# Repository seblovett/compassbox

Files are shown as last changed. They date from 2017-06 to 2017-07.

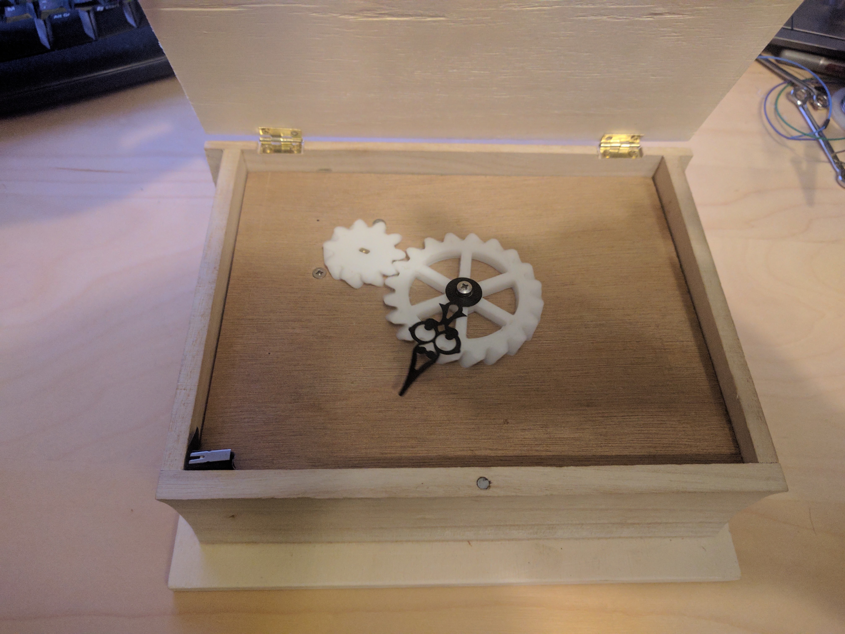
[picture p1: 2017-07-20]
Photos/IMG_20170703_221253.jpg

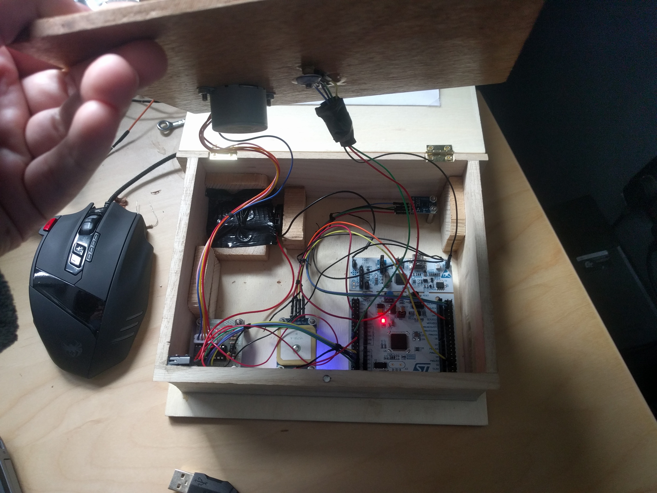
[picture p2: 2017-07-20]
Photos/IMG_20170714_074107.jpg

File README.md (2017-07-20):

# CompassBox

This is a box which I made as a wedding present. When functioning it points back to where the couple exchanged their vows. 

I originally got the idea from http://hackaday.com/2016/11/05/personal-compass-points-to-your-spawn-point/. The one aspect I didn't like about the original design was the use of the servo motor and meant it could not turn continually. 

I opted for the use of a stepper motor and integrate a zero location sensor which is a opto sensor. 

4 PCBs in the box under the false bottom:
 - STM32 Nucleo board
 - I2C Magnetometer 
 - GPS
 - Motor driver

There is also a microswitch which controls the power to the entire system.

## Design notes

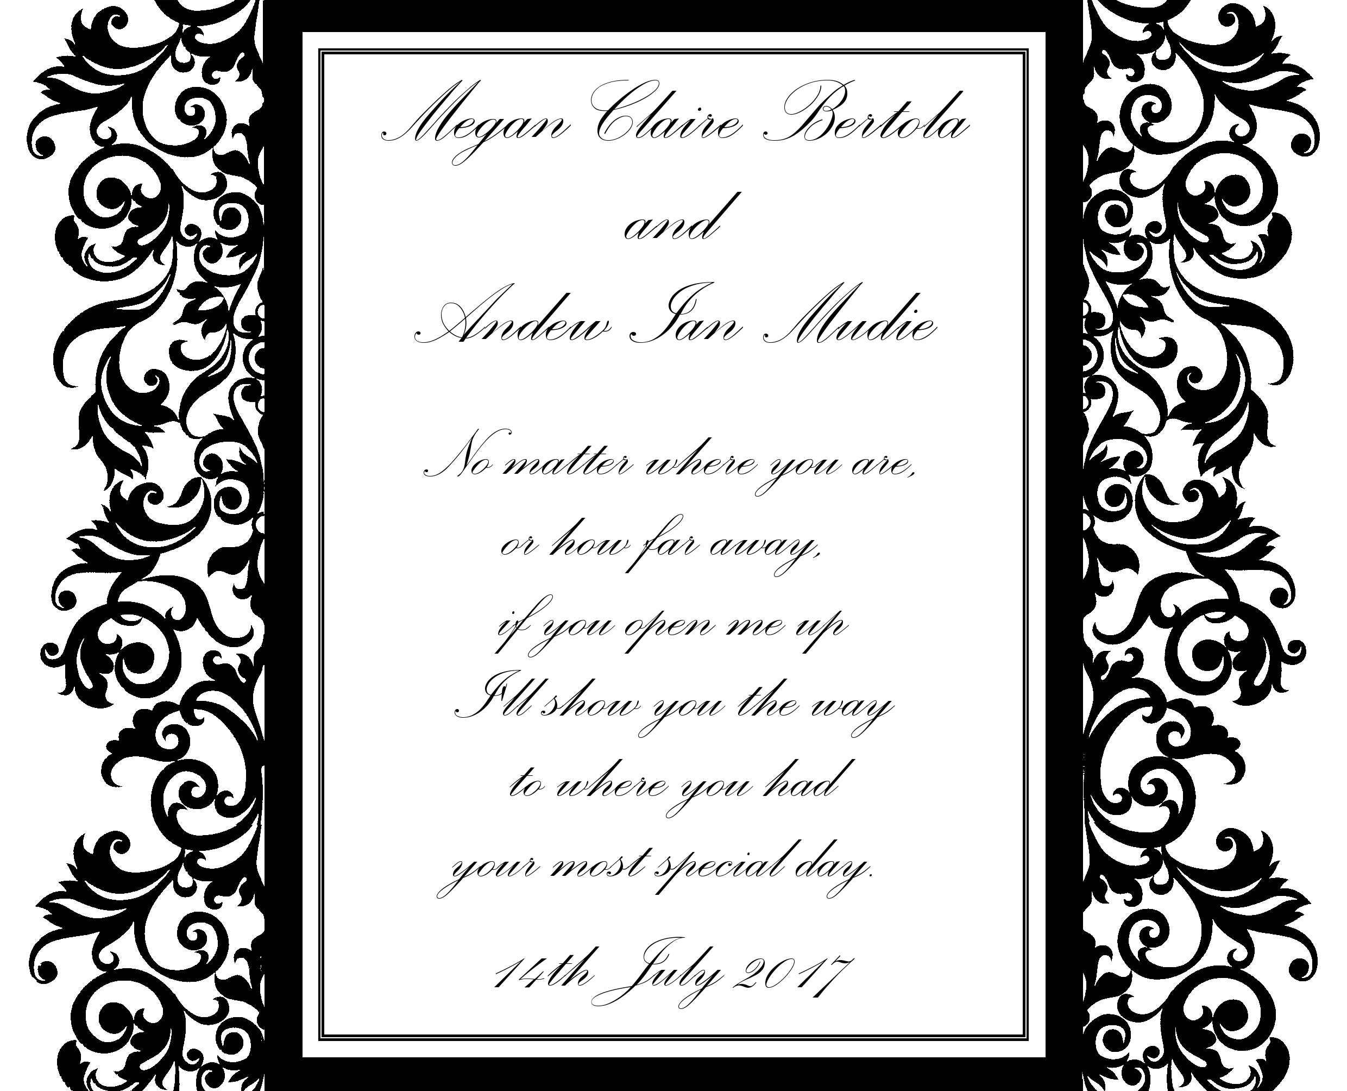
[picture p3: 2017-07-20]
Images/AandM.png

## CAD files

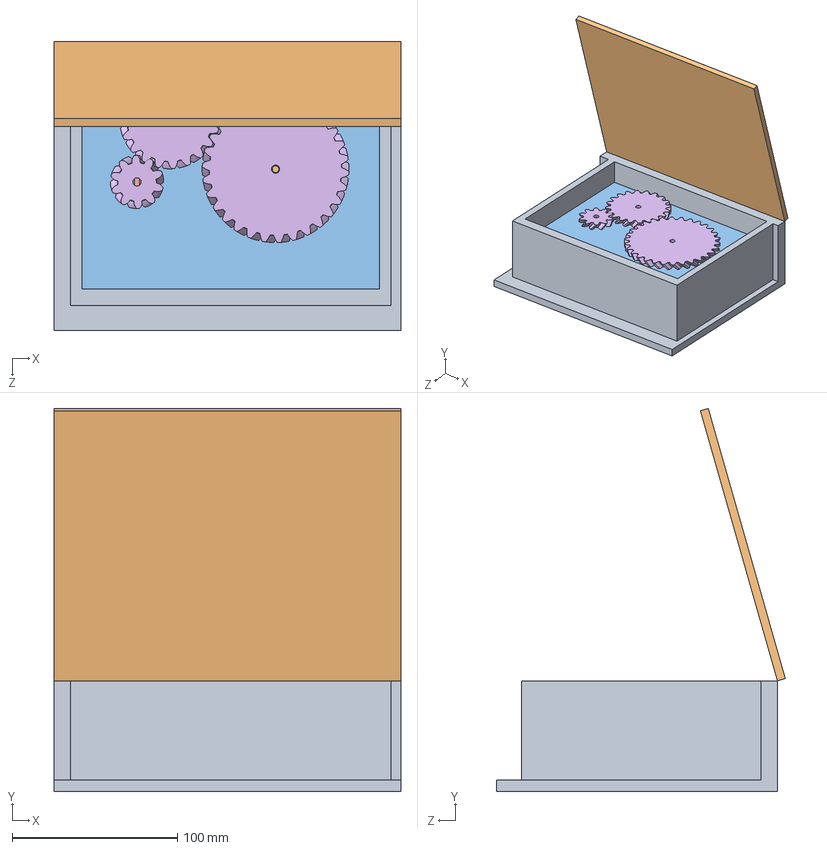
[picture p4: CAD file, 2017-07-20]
Mechanics/complete.SLDASM
210.0 x 231.8 x 174.8 mm
box_base
Lid
zerolocator
motor
helical gear_3_am x 3
compass
gps_module
motor_driver
nucleo

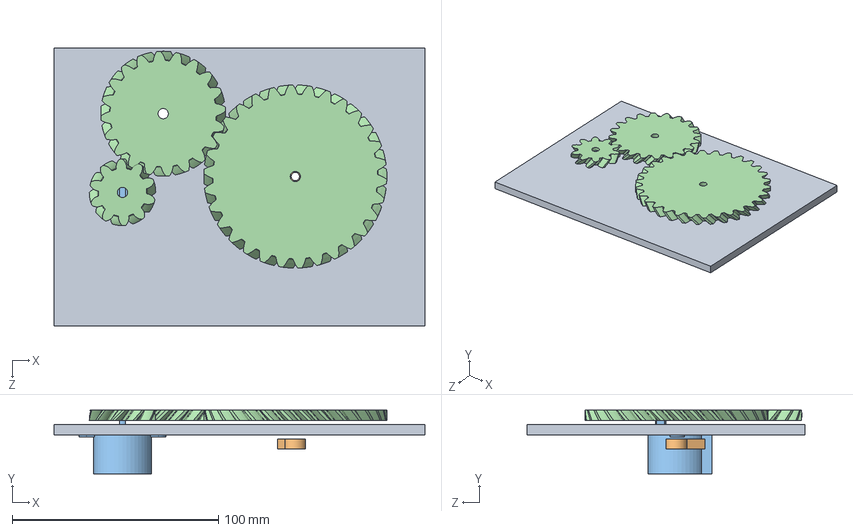
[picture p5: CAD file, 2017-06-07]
Mechanics/boxcompass.SLDASM
180.0 x 31.0 x 135.0 mm
Lid
zerolocator
motor
helical gear_3_am x 3

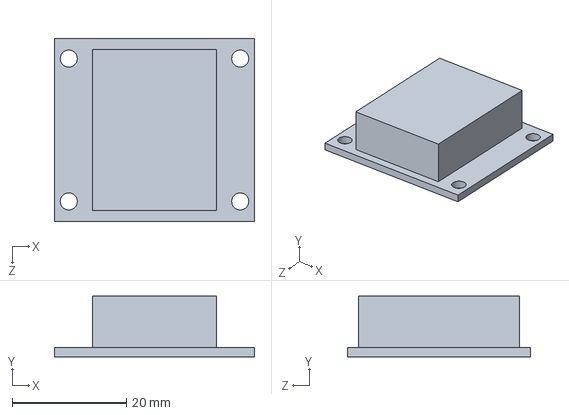
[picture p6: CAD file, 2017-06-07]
Mechanics/motor_driver.SLDPRT
35.0 x 10.6 x 32.0 mm

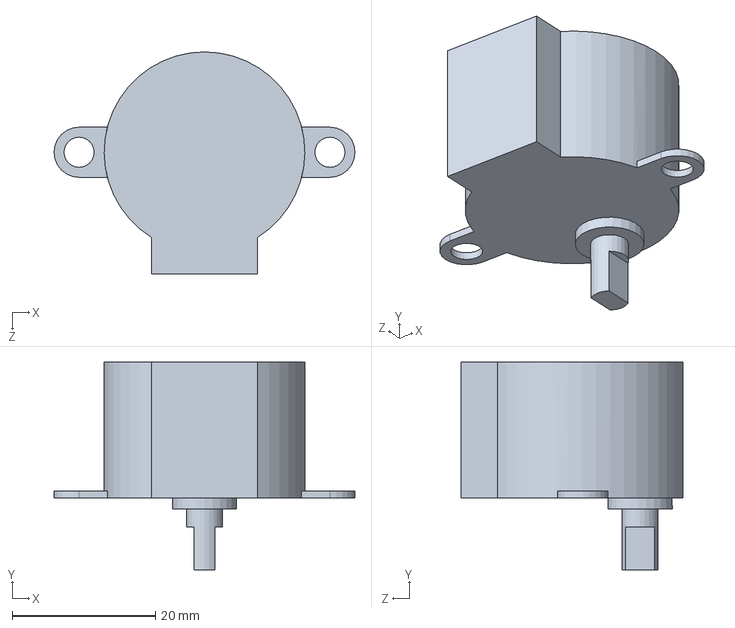
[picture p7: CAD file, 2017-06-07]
Mechanics/motor.SLDPRT
42.0 x 29.0 x 31.0 mm

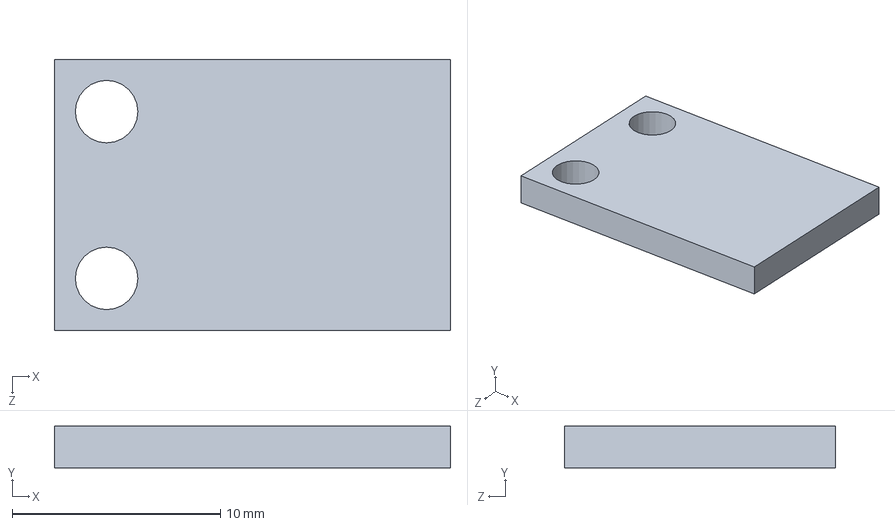
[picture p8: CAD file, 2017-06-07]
Mechanics/compass.SLDPRT
19.0 x 2.00 x 13.0 mm

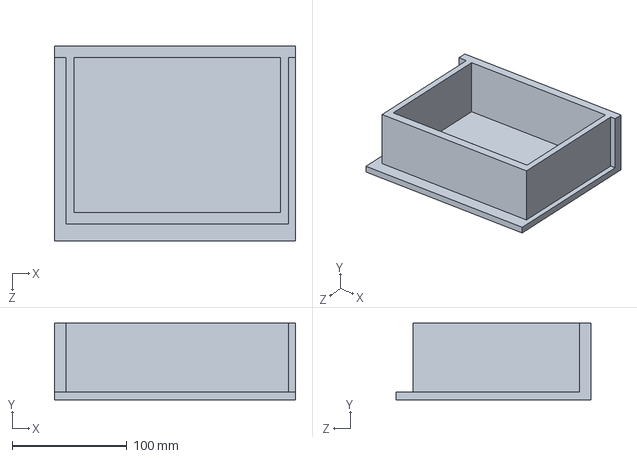
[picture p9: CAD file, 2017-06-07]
Mechanics/box_base.SLDPRT
210.0 x 67.0 x 170.0 mm

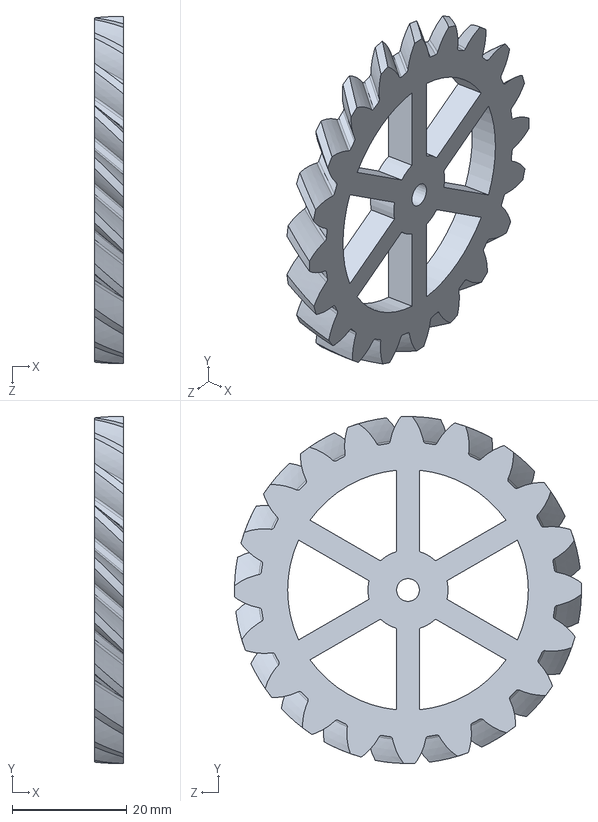
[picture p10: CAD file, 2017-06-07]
Mechanics/helical_med.SLDPRT
5.00 x 60.6 x 60.6 mm

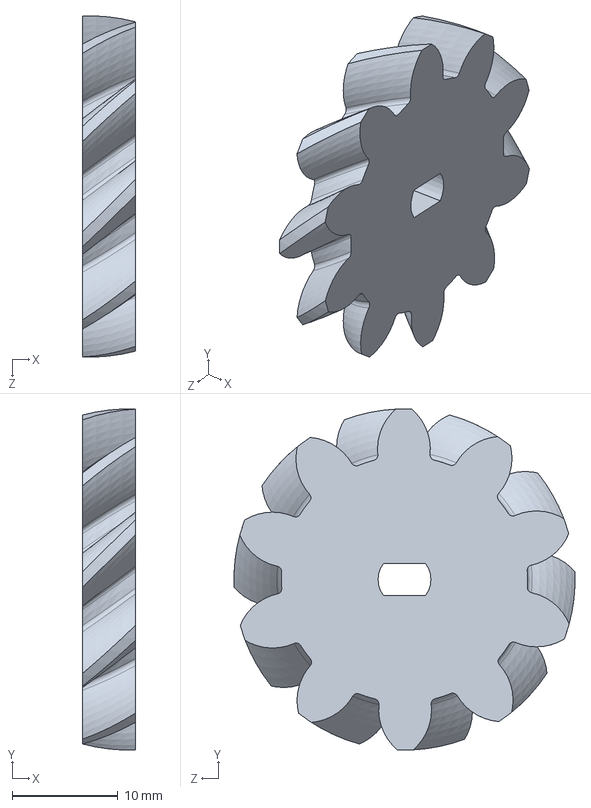
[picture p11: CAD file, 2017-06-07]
Mechanics/helical_small.SLDPRT
5.00 x 32.3 x 32.3 mm

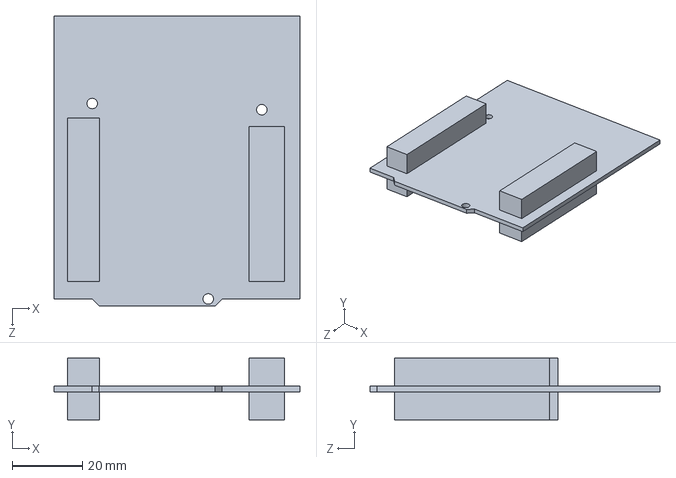
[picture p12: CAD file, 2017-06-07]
Mechanics/nucleo.SLDPRT
70.0 x 17.6 x 82.5 mm

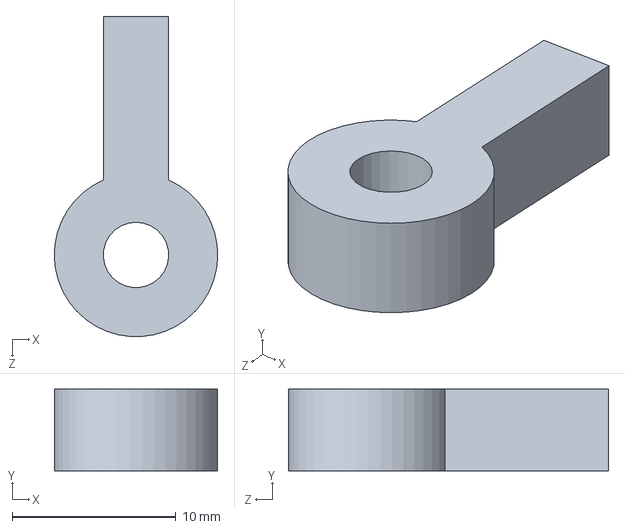
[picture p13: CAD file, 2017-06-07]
Mechanics/zerolocator.SLDPRT
10.00 x 5.00 x 19.6 mm

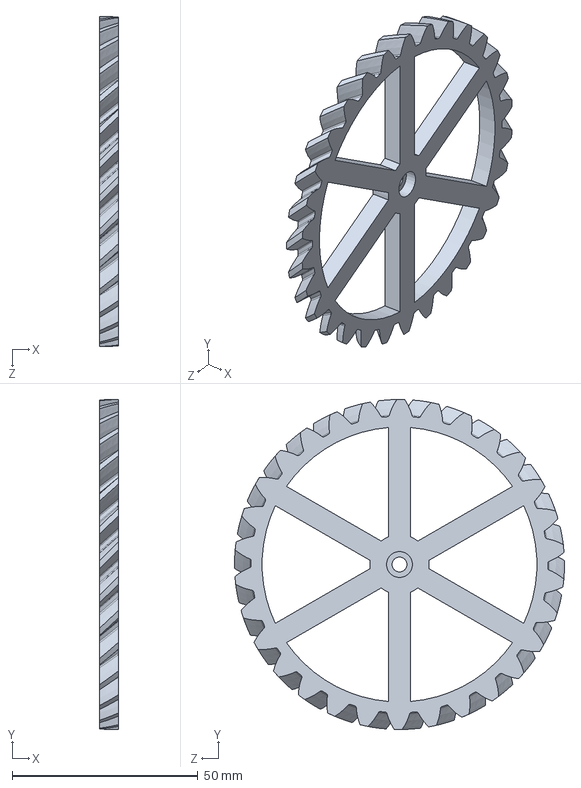
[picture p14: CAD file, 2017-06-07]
Mechanics/helical_large.SLDPRT
5.00 x 88.9 x 88.8 mm

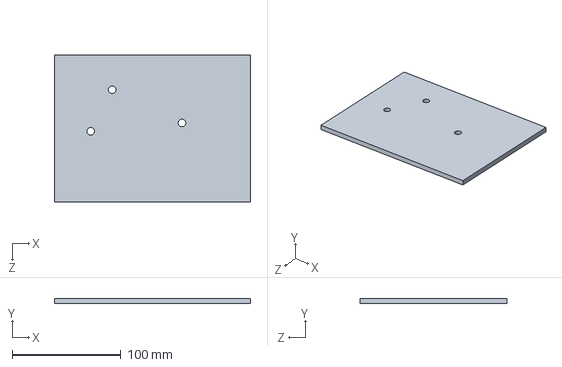
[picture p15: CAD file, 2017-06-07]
Mechanics/Lid.SLDPRT
180.0 x 5.00 x 135.0 mm

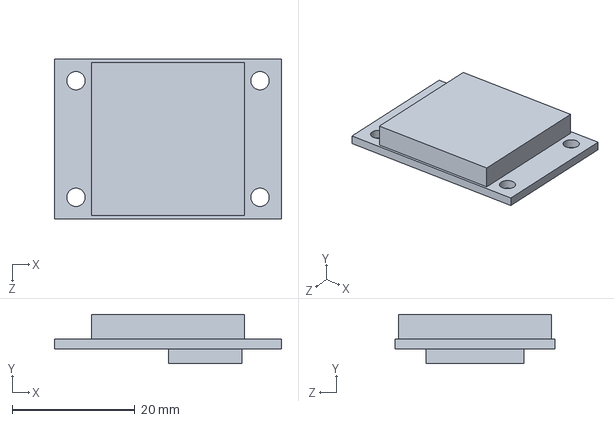
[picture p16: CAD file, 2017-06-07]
Mechanics/gps_module.SLDPRT
37.0 x 8.00 x 26.0 mm

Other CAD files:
Mechanics/helical_large.STL
Mechanics/helical_med.STL
Mechanics/helical_small.STL
Mechanics/zerolocator.STL

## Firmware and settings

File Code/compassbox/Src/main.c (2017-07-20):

/**
  ******************************************************************************
  * File Name          : main.c
  * Description        : Main program body
  ******************************************************************************
  *
  * COPYRIGHT(c) 2017 STMicroelectronics
  *
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
  ******************************************************************************
  */
/* Includes ------------------------------------------------------------------*/
#include "stm32f3xx_hal.h"

/* USER CODE BEGIN Includes */
#include "compass.h"

#include "nmea/info.h"

#include "nmea/parser.h"

#include "nmea/gmath.h"

#include "motor.h"
/* USER CODE END Includes */

I2C_HandleTypeDef hi2c1;

TIM_HandleTypeDef htim6;

UART_HandleTypeDef huart1;
UART_HandleTypeDef huart2;

/* USER CODE BEGIN PV */
#define GPS_BUFFSIZE 256
nmeaPOS dest_pos = {
		.lat = 51.248596,
		.lon = -0.716903
};



/* USER CODE END PV */

void SystemClock_Config(void);
void Error_Handler(void);
static void MX_GPIO_Init(void);
static void MX_I2C1_Init(void);
static void MX_USART1_UART_Init(void);
static void MX_USART2_UART_Init(void);
static void MX_TIM6_Init(void);

/* USER CODE BEGIN PFP */
bool get_location(nmeaPOS *pos);
int16_t angleFromCoordinate(nmeaPOS *pos1, nmeaPOS *pos2);
/* USER CODE END PFP */

/* USER CODE BEGIN 0 */

typedef enum {
	STARTUP = 0,
	ZERO_MOTORS,
	GET_FIX,
	ACTIVE,
	COMPASS_ERROR = -1
} state_t;

int _write(int file, char *data, int len) {   // arbitrary timeout 1000
	HAL_StatusTypeDef status = HAL_UART_Transmit(&huart2, (uint8_t*) data, len,
			1);

	// return # of bytes written - as best we can tell
	return (status == HAL_OK ? len : 0);
}

bool _cmd_rcvd;
//#define TEST
/* USER CODE END 0 */

int main(void)
{

  /* USER CODE BEGIN 1 */
	_cmd_rcvd = false;
	nmeaPOS gps_pos = {0.0,0.0};
	state_t state = STARTUP;
  /* USER CODE END 1 */

  /* MCU Configuration----------------------------------------------------------*/

  /* Reset of all peripherals, Initializes the Flash interface and the Systick. */
  HAL_Init();

  /* Configure the system clock */
  SystemClock_Config();

  /* Initialize all configured peripherals */
  MX_GPIO_Init();
  MX_I2C1_Init();
  MX_USART1_UART_Init();
  MX_USART2_UART_Init();
  MX_TIM6_Init();

  /* USER CODE BEGIN 2 */
	printf("Compass\n\r");
//	zero_motor();
//	compass_init(&hi2c1);
//	while(1)
//	{
//		printf("C = %d\n\r",compass_get_heading());
//		HAL_Delay(1000);
//	}
  /* USER CODE END 2 */

  /* Infinite loop */
  /* USER CODE BEGIN WHILE */
	get_location(&gps_pos);//i think it is reasonable that the unit isn't going to move in this situation, at least not by enough we'll care

	int16_t current_bearing = 0;
	int16_t resolved_angle = 0;
	while (1)
	{
		switch(state)
		{
		case STARTUP:
			printf("Start up\n\r");
			compass_init(&hi2c1);
			state = ZERO_MOTORS;
			break;
		case ZERO_MOTORS:
			printf("Zeroing motors\n\r");
			if(zero_motor())
			{
				state = GET_FIX;
#ifdef TEST
				state = ACTIVE;
#endif
			}
			else
			{
				state = COMPASS_ERROR;
			}
			break;
		case GET_FIX:
			printf("Get fix\n\r");
//			get_location(&gps_pos);//i think it is reasonable that the unit isn't going to move in this situation, at least not by enough we'll care
			resolved_angle = angleFromCoordinate(&gps_pos, &dest_pos);
			printf("A= %d\n\r", resolved_angle);

			//@todo implement a timeout
			state = ACTIVE;
			break;
		case ACTIVE:
			printf("Active!!\n\r");
			current_bearing = compass_get_heading() - 180;
//			for now, we'll assume there is 0 fudge factor between the compass and box
			printf("C = %d,p = %d\n\r", current_bearing, resolved_angle - current_bearing);
			set_target((resolved_angle - current_bearing + 360)%360);
			break;

		default:
			printf("Error occurred...\n\r");
			while(1);
			return 1;
		}
		HAL_Delay(500);
//	  test_motors();
//	  HAL_Delay(1000);
  /* USER CODE END WHILE */

  /* USER CODE BEGIN 3 */

	}
  /* USER CODE END 3 */

}

/** System Clock Configuration
*/
void SystemClock_Config(void)
{

  RCC_OscInitTypeDef RCC_OscInitStruct;
  RCC_ClkInitTypeDef RCC_ClkInitStruct;
  RCC_PeriphCLKInitTypeDef PeriphClkInit;

  RCC_OscInitStruct.OscillatorType = RCC_OSCILLATORTYPE_HSI;
  RCC_OscInitStruct.HSIState = RCC_HSI_ON;
  RCC_OscInitStruct.HSICalibrationValue = 16;
  RCC_OscInitStruct.PLL.PLLState = RCC_PLL_ON;
  RCC_OscInitStruct.PLL.PLLSource = RCC_PLLSOURCE_HSI;
  RCC_OscInitStruct.PLL.PLLMUL = RCC_PLL_MUL16;
  if (HAL_RCC_OscConfig(&RCC_OscInitStruct) != HAL_OK)
  {
    Error_Handler();
  }

  RCC_ClkInitStruct.ClockType = RCC_CLOCKTYPE_HCLK|RCC_CLOCKTYPE_SYSCLK
                              |RCC_CLOCKTYPE_PCLK1|RCC_CLOCKTYPE_PCLK2;
  RCC_ClkInitStruct.SYSCLKSource = RCC_SYSCLKSOURCE_PLLCLK;
  RCC_ClkInitStruct.AHBCLKDivider = RCC_SYSCLK_DIV1;
  RCC_ClkInitStruct.APB1CLKDivider = RCC_HCLK_DIV2;
  RCC_ClkInitStruct.APB2CLKDivider = RCC_HCLK_DIV1;
  if (HAL_RCC_ClockConfig(&RCC_ClkInitStruct, FLASH_LATENCY_2) != HAL_OK)
  {
    Error_Handler();
  }

  PeriphClkInit.PeriphClockSelection = RCC_PERIPHCLK_USART1|RCC_PERIPHCLK_I2C1;
  PeriphClkInit.Usart1ClockSelection = RCC_USART1CLKSOURCE_PCLK1;
  PeriphClkInit.I2c1ClockSelection = RCC_I2C1CLKSOURCE_HSI;
  if (HAL_RCCEx_PeriphCLKConfig(&PeriphClkInit) != HAL_OK)
  {
    Error_Handler();
  }

  HAL_SYSTICK_Config(HAL_RCC_GetHCLKFreq()/1000);

  HAL_SYSTICK_CLKSourceConfig(SYSTICK_CLKSOURCE_HCLK);

  /* SysTick_IRQn interrupt configuration */
  HAL_NVIC_SetPriority(SysTick_IRQn, 0, 0);
}

/* I2C1 init function */
static void MX_I2C1_Init(void)
{

  hi2c1.Instance = I2C1;
  hi2c1.Init.Timing = 0x2000090E;
  hi2c1.Init.OwnAddress1 = 0;
  hi2c1.Init.AddressingMode = I2C_ADDRESSINGMODE_7BIT;
  hi2c1.Init.DualAddressMode = I2C_DUALADDRESS_DISABLE;
  hi2c1.Init.OwnAddress2 = 0;
  hi2c1.Init.OwnAddress2Masks = I2C_OA2_NOMASK;
  hi2c1.Init.GeneralCallMode = I2C_GENERALCALL_DISABLE;
  hi2c1.Init.NoStretchMode = I2C_NOSTRETCH_DISABLE;
  if (HAL_I2C_Init(&hi2c1) != HAL_OK)
  {
    Error_Handler();
  }

    /**Configure Analogue filter 
    */
  if (HAL_I2CEx_ConfigAnalogFilter(&hi2c1, I2C_ANALOGFILTER_ENABLE) != HAL_OK)
  {
    Error_Handler();
  }

}

/* TIM6 init function */
static void MX_TIM6_Init(void)
{

  TIM_MasterConfigTypeDef sMasterConfig;

  htim6.Instance = TIM6;
  htim6.Init.Prescaler = 1;
  htim6.Init.CounterMode = TIM_COUNTERMODE_UP;
  htim6.Init.Period = 255;
  if (HAL_TIM_Base_Init(&htim6) != HAL_OK)
  {
    Error_Handler();
  }

  sMasterConfig.MasterOutputTrigger = TIM_TRGO_RESET;
  sMasterConfig.MasterSlaveMode = TIM_MASTERSLAVEMODE_DISABLE;
  if (HAL_TIMEx_MasterConfigSynchronization(&htim6, &sMasterConfig) != HAL_OK)
  {
    Error_Handler();
  }

}

/* USART1 init function */
static void MX_USART1_UART_Init(void)
{

  huart1.Instance = USART1;
  huart1.Init.BaudRate = 9600;
  huart1.Init.WordLength = UART_WORDLENGTH_8B;
  huart1.Init.StopBits = UART_STOPBITS_1;
  huart1.Init.Parity = UART_PARITY_NONE;
  huart1.Init.Mode = UART_MODE_TX_RX;
  huart1.Init.HwFlowCtl = UART_HWCONTROL_NONE;
  huart1.Init.OverSampling = UART_OVERSAMPLING_16;
  huart1.Init.OneBitSampling = UART_ONE_BIT_SAMPLE_DISABLE;
  huart1.AdvancedInit.AdvFeatureInit = UART_ADVFEATURE_NO_INIT;
  if (HAL_UART_Init(&huart1) != HAL_OK)
  {
    Error_Handler();
  }

}

/* USART2 init function */
static void MX_USART2_UART_Init(void)
{

  huart2.Instance = USART2;
  huart2.Init.BaudRate = 115200;
  huart2.Init.WordLength = UART_WORDLENGTH_8B;
  huart2.Init.StopBits = UART_STOPBITS_1;
  huart2.Init.Parity = UART_PARITY_NONE;
  huart2.Init.Mode = UART_MODE_TX_RX;
  huart2.Init.HwFlowCtl = UART_HWCONTROL_NONE;
  huart2.Init.OverSampling = UART_OVERSAMPLING_16;
  huart2.Init.OneBitSampling = UART_ONE_BIT_SAMPLE_DISABLE;
  huart2.AdvancedInit.AdvFeatureInit = UART_ADVFEATURE_NO_INIT;
  if (HAL_UART_Init(&huart2) != HAL_OK)
  {
    Error_Handler();
  }

}

/** Configure pins as 
        * Analog 
        * Input 
        * Output
        * EVENT_OUT
        * EXTI
*/
static void MX_GPIO_Init(void)
{

  GPIO_InitTypeDef GPIO_InitStruct;

  /* GPIO Ports Clock Enable */
  __HAL_RCC_GPIOC_CLK_ENABLE();
  __HAL_RCC_GPIOF_CLK_ENABLE();
  __HAL_RCC_GPIOA_CLK_ENABLE();
  __HAL_RCC_GPIOB_CLK_ENABLE();

  /*Configure GPIO pin : B1_Pin */
  GPIO_InitStruct.Pin = B1_Pin;
  GPIO_InitStruct.Mode = GPIO_MODE_EVT_RISING;
  GPIO_InitStruct.Pull = GPIO_NOPULL;
  HAL_GPIO_Init(B1_GPIO_Port, &GPIO_InitStruct);

  /*Configure GPIO pins : MOTOR_1_Pin MOTOR_2_Pin testpin_Pin */
  GPIO_InitStruct.Pin = MOTOR_1_Pin|MOTOR_2_Pin|testpin_Pin;
  GPIO_InitStruct.Mode = GPIO_MODE_OUTPUT_PP;
  GPIO_InitStruct.Pull = GPIO_NOPULL;
  GPIO_InitStruct.Speed = GPIO_SPEED_FREQ_LOW;
  HAL_GPIO_Init(GPIOC, &GPIO_InitStruct);

  /*Configure GPIO pin : COMPASS_ZERO_Pin */
  GPIO_InitStruct.Pin = COMPASS_ZERO_Pin;
  GPIO_InitStruct.Mode = GPIO_MODE_INPUT;
  GPIO_InitStruct.Pull = GPIO_NOPULL;
  HAL_GPIO_Init(COMPASS_ZERO_GPIO_Port, &GPIO_InitStruct);

  /*Configure GPIO pin : MOTOR_4_Pin */
  GPIO_InitStruct.Pin = MOTOR_4_Pin;
  GPIO_InitStruct.Mode = GPIO_MODE_OUTPUT_PP;
  GPIO_InitStruct.Pull = GPIO_NOPULL;
  GPIO_InitStruct.Speed = GPIO_SPEED_FREQ_LOW;
  HAL_GPIO_Init(MOTOR_4_GPIO_Port, &GPIO_InitStruct);

  /*Configure GPIO pins : MOTOR_3_Pin LD2_Pin */
  GPIO_InitStruct.Pin = MOTOR_3_Pin|LD2_Pin;
  GPIO_InitStruct.Mode = GPIO_MODE_OUTPUT_PP;
  GPIO_InitStruct.Pull = GPIO_NOPULL;
  GPIO_InitStruct.Speed = GPIO_SPEED_FREQ_LOW;
  HAL_GPIO_Init(GPIOB, &GPIO_InitStruct);

  /*Configure GPIO pins : PB14 ZERO_Pin */
  GPIO_InitStruct.Pin = GPIO_PIN_14|ZERO_Pin;
  GPIO_InitStruct.Mode = GPIO_MODE_INPUT;
  GPIO_InitStruct.Pull = GPIO_NOPULL;
  HAL_GPIO_Init(GPIOB, &GPIO_InitStruct);

  /*Configure GPIO pin Output Level */
  HAL_GPIO_WritePin(GPIOC, MOTOR_1_Pin|MOTOR_2_Pin|testpin_Pin, GPIO_PIN_RESET);

  /*Configure GPIO pin Output Level */
  HAL_GPIO_WritePin(MOTOR_4_GPIO_Port, MOTOR_4_Pin, GPIO_PIN_RESET);

  /*Configure GPIO pin Output Level */
  HAL_GPIO_WritePin(GPIOB, MOTOR_3_Pin|LD2_Pin, GPIO_PIN_RESET);

}

/* USER CODE BEGIN 4 */
void HAL_UART_RxCpltCallback(UART_HandleTypeDef *huart)
{
	_cmd_rcvd = true;
}

int16_t angleFromCoordinate(nmeaPOS *from, nmeaPOS *to)
{
	//convert to rads
	double long1, long2, lat1, lat2;
	long1 = nmea_degree2radian(from->lon);
	lat1 = nmea_degree2radian(from->lat);
	long2 = nmea_degree2radian(to->lon);
	lat2 = nmea_degree2radian(to->lat);
	double dLon = (long2 - long1);

	double y = sin(dLon) * cos(lat2);
	double x = cos(lat1) * sin(lat2) - sin(lat1)* cos(lat2) * cos(dLon);

	double brng = atan2(y, x);

	brng = nmea_radian2degree(brng);
	int16_t result = (((int16_t)brng + 360) % 360);
	//brng = 360 - brng; // count degrees counter-clockwise - remove to make clockwise

	return result;
}

bool get_location(nmeaPOS *pos)
{
	nmeaINFO info;
	nmeaPARSER parser;
	bool has_lock = false;
	nmea_zero_INFO(&info);
	nmea_parser_init(&parser);
	uint8_t data[GPS_BUFFSIZE] = { 0 };
	uint8_t ptr = 0;
	uint8_t data_b = 0;

	//get a command from GPS
	data_b = 0;
	memset(data, 0, GPS_BUFFSIZE);
	ptr = 0;
	//wait for a $
	while(data_b != '$')
	{
		data_b = 0;
		HAL_UART_Receive(&huart1, &data_b, 1, 10000);
	}
	data[ptr++] = data_b;
	while(!has_lock)
	{
		//put all data in a buffer
		if(HAL_OK == HAL_UART_Receive(&huart1, &data_b, 1, 1))
		{
			data[ptr++] = data_b;
			// until received a \n
			if((data_b == '\n') || (data_b == '\r'))
			{
				nmea_parse(&parser, (char *)data, (int)strlen((char *)data), &info);
			}
		}

		if(info.sig == 1)//has fix
		{
			has_lock = true;
		}
	}
	//fix got!
	pos->lat = nmea_ndeg2degree(info.lat);
	pos->lon = nmea_ndeg2degree(info.lon);
	printf("Fix obtained: LAT:%f, LON:%f, UTC:%d:%d, dec:%f\n\r", pos->lat, pos->lon, info.utc.hour, info.utc.min, info.declination);
	return true;
}


/* USER CODE END 4 */
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


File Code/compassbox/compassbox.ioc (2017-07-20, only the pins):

Mcu.UserName=STM32F302R8Tx
PA1.GPIO_Label=COMPASS_ZERO
PA1.Signal=GPIO_Input
PA10.GPIO_Label=GPS_RX
PA10.Signal=USART1_RX
PA13.GPIO_Label=TMS
PA13.Signal=SYS_JTMS-SWDIO
PA14.GPIO_Label=TCK
PA14.Signal=SYS_JTCK-SWCLK
PA2.GPIO_Label=USART_TX
PA2.Signal=USART2_TX
PA3.GPIO_Label=USART_RX
PA3.Signal=USART2_RX
PA4.GPIO_Label=MOTOR_4
PA4.Signal=GPIO_Output
PB0.GPIO_Label=MOTOR_3
PB0.Signal=GPIO_Output
PB13.GPIO_Label=LD2 [Green Led]
PB13.Signal=GPIO_Output
PB14.Signal=GPIO_Input
PB3.GPIO_Label=SWO
PB3.Signal=SYS_JTDO-TRACESWO
PB6.GPIO_Label=GPS_TX
PB6.Signal=USART1_TX
PB7.GPIO_Label=ZERO
PB7.Signal=GPIO_Input
PB8.GPIO_Label=I2C_SCL
PB8.Signal=I2C1_SCL
PB9.GPIO_Label=I2C_SCA
PB9.Signal=I2C1_SDA
PC0.GPIO_Label=MOTOR_1
PC0.Signal=GPIO_Output
PC1.GPIO_Label=MOTOR_2
PC1.Signal=GPIO_Output
PC13.GPIO_Label=B1 [Blue PushButton]
PC13.Signal=GPXTI13
PC4.GPIO_Label=testpin
PC4.Signal=GPIO_Output
PF0-OSC_IN.Signal=RCC_OSC_IN
PF1-OSC_OUT.Signal=RCC_OSC_OUT

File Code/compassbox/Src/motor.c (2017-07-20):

#include <stdlib.h>
#include "motor.h"
#include "mxconstants.h"
#include "stm32f3xx_hal.h"


#define STEPS_PER_FULL		64
#define INTERNAL_GEAR_RATIO	64
#define OUTPUT_GEAR_RATIO	2
#define STEP_ANGLE			(double)(360.0 / (double)(STEPS_PER_FULL*INTERNAL_GEAR_RATIO*OUTPUT_GEAR_RATIO))

#define STEPS_PER_ROTATION	(STEPS_PER_FULL * INTERNAL_GEAR_RATIO * OUTPUT_GEAR_RATIO )

int16_t current_angle_deg = 0;
int16_t target_angle_deg = 0;
uint32_t target_step_count = 0;
uint32_t step_count = 0;
bool direction = false;

bool motor_running = false;

uint32_t step_interval = 0;
uint32_t target_interval = 0;

#define MIN_SPEED 0x8000
#define MAX_SPEED 0x4000

#define MOTOR_SEQ_COUNT		8
uint8_t motor_movement_cw [MOTOR_SEQ_COUNT] =
						   {
								   0b1000,
								   0b1100,
								   0b0100,
								   0b0110,
								   0b0010,
								   0b0011,
								   0b0001,
								   0b1001
						   };



void HAL_TIM_PeriodElapsedCallback(TIM_HandleTypeDef *htim)
{
//	HAL_GPIO_TogglePin(testpin_GPIO_Port, testpin_Pin);
	if(target_step_count == step_count)
	{
		motors_off();
		motor_running = false;
		HAL_TIM_Base_Stop_IT(&htim6);
	}
	else{

	if(direction)
		step_cw();
	else
		step_acw();
	}
}


void set_target(int16_t target_deg)
{
	target_angle_deg = target_deg;
	target_step_count = (uint32_t)((double)target_angle_deg / STEP_ANGLE);
	current_angle_deg = step_count * STEP_ANGLE;
	bool dir = (angle_difference(current_angle_deg, target_angle_deg) > 0);
	printf("t=%d:%d, c=%d:%d\n\r", target_angle_deg, target_step_count, current_angle_deg, step_count);
	if(dir)
	printf("cw\n\r");
	else
		printf("acw\n\r");
	set_speed(100, dir);
}

bool motors_running()
{
	return motor_running;
}
//@param speed 0-255 (0 being off) linear scale between off and full speed
//@param clockwise - direction to rotate
void set_speed(uint8_t speed, bool cw_nacw)
{
	direction = cw_nacw;
	if(0 == speed)
	{
		motors_off();
		motor_running = false;
		HAL_TIM_Base_Stop_IT(&htim6);
	}
	else
	{
		htim6.Instance->ARR = MIN_SPEED;
//		htim6.Instance->ARR = (MIN_SPEED - ((MIN_SPEED - MAX_SPEED) / (256 - (uint32_t)speed)));
		if(!motor_running)
		{
			HAL_TIM_Base_Start_IT(&htim6);
			motor_running = true;
		}
	}
}

bool get_zero_state()
{
	return (HAL_GPIO_ReadPin(ZERO_GPIO_Port, ZERO_Pin) == GPIO_PIN_RESET);
}

void motors_off()
{
	HAL_GPIO_WritePin(MOTOR_1_GPIO_Port,MOTOR_1_Pin, GPIO_PIN_RESET);
	HAL_GPIO_WritePin(MOTOR_2_GPIO_Port,MOTOR_2_Pin, GPIO_PIN_RESET);
	HAL_GPIO_WritePin(MOTOR_3_GPIO_Port,MOTOR_3_Pin, GPIO_PIN_RESET);
	HAL_GPIO_WritePin(MOTOR_4_GPIO_Port,MOTOR_4_Pin, GPIO_PIN_RESET);
}

void write_motors(uint8_t state)
{
	motors_off();
	if(state & 0x01)
	{
		HAL_GPIO_WritePin(MOTOR_1_GPIO_Port,MOTOR_1_Pin, GPIO_PIN_SET);
	}
//	else
//	{
//		HAL_GPIO_WritePin(MOTOR_1_GPIO_Port,MOTOR_1_Pin, GPIO_PIN_RESET);
//	}

	if(state & 0x02)
	{
		HAL_GPIO_WritePin(MOTOR_2_GPIO_Port,MOTOR_2_Pin, GPIO_PIN_SET);
	}
//	else
//	{
//		HAL_GPIO_WritePin(MOTOR_2_GPIO_Port,MOTOR_2_Pin, GPIO_PIN_RESET);
//	}

	if(state & 0x04)
	{
		HAL_GPIO_WritePin(MOTOR_3_GPIO_Port,MOTOR_3_Pin, GPIO_PIN_SET);
	}
//	else
//	{
//		HAL_GPIO_WritePin(MOTOR_3_GPIO_Port,MOTOR_3_Pin, GPIO_PIN_RESET);
//	}

	if(state & 0x08)
	{
		HAL_GPIO_WritePin(MOTOR_4_GPIO_Port,MOTOR_4_Pin, GPIO_PIN_SET);
	}
//	else
//	{
//		HAL_GPIO_WritePin(MOTOR_4_GPIO_Port,MOTOR_4_Pin, GPIO_PIN_RESET);
//	}
}

void step_acw()
{
	uint8_t i = --step_count%8; //0-7 val
	write_motors(motor_movement_cw[i]);
	step_count %= STEPS_PER_ROTATION;
}

void step_cw()
{
	write_motors(motor_movement_cw[step_count++%8]);
	step_count %= STEPS_PER_ROTATION;
}


bool zero_motor()
{
	//get us to zero location
	//if we are already at 0, move 10degrees acw first
	while(get_zero_state())
	{
		step_acw();
		HAL_Delay(1);
	}

	//rotate clockwise until the zero location is triggered
	while(!get_zero_state())
	{
		step_cw();
		HAL_Delay(1);
	}
	 motors_off();
	 current_angle_deg = 0;
	 step_count = 0;

	return true;
}


int16_t angle_difference(int16_t b1, int16_t b2) {
    int16_t r = (b2 - b1) % 360;
    if (r < -180) {
      r += 360;
    }
    if (r >= 180) {
      r -= 360;
    }
    return r;
}

void move_motor(int16_t angle)
{
	//move motor to a specified angle

	int16_t angle_to_move = angle_difference(current_angle_deg, angle);
	bool cw_nacw= angle_to_move > 0; //this is clockwise or not.
	angle_to_move = abs(angle_to_move);
	printf("From %d to %d = %d\n\r", current_angle_deg, angle, angle_to_move);
	uint16_t steps = (int16_t)((double)(angle_to_move) / STEP_ANGLE);
	printf("Moving %d steps\n\r", steps);
	if(!cw_nacw)
	{
		printf("anti");
	}
	printf("clockwise\n\r");
	for(uint32_t i = 0; i < steps; i++)
	{
		step_motor(cw_nacw);
		HAL_Delay(1);
	}
	current_angle_deg = angle;
}



void test_motors()
{
	for(uint32_t i = 0; i < INTERNAL_GEAR_RATIO * STEPS_PER_FULL; i++)
		{
			write_motors(motor_movement_cw[i%8]);
			HAL_Delay(1);
		}
	motors_off();
	HAL_Delay(1000);
	for(uint32_t i = 0; i < INTERNAL_GEAR_RATIO * STEPS_PER_FULL; i++)
	{
		write_motors(motor_movement_cw[7-i%8]);
		HAL_Delay(1);
	}
	motors_off();
	move_motor(45);
	move_motor(90);
	move_motor(0);
	move_motor(240);
	move_motor(45);
	move_motor(0);
	HAL_Delay(1000);
}

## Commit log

2017-06-07 Initial commit of all files
    [Lid.SLDPRT, box_base.SLDPRT, boxcompass.SLDASM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]
2017-07-20 Update of software and box image
    [complete.SLDASM]
2019-03-14 Added V1 of actual PCB
    Full design files from Circuit Studio and combined 2 up panel gerbers added
    [Compass.PrjPcb, Compass.SchDoc]

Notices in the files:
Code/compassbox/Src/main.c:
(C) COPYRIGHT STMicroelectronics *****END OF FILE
